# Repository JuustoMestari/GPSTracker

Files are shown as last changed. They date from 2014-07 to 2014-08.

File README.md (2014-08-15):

GPSTracker
==========

## Arduino

Arduino Pro mini 3.3V 8Mhz ( copy )

### Libraries

#### SoftwareSerial

In order to run the code properly, you need to modify **SoftwareSerial.h** (Arduino\libraries\SoftwareSerial) before compiling.
At line **42** change _SS_MAX_RX_BUFF to 256 : `#define _SS_MAX_RX_BUFF 256 `

#### NeoPixel

Please use the library in this repo. It has been modified to use Analog Port as well (Leds are connected to Analog 5)
If you want to make the modification yourself, replace all **PORTB** by **PORTC**  in Adafruit_NeoPixel.cpp (You won't be able to use the library with ports 8 to 13 tho...)
* Make a backup of the original file and use the modified version only to compile for this project !

[See here for port manipulation](http://www.arduino.cc/en/Reference/PortManipulation)

## Hardware

### TP4056

* Green LED ON - Red LED Blink -> **No battery**
* RED LED ON -> **Loading**
* GREEN LED ON -> **Loaded**

The module in this project uses a mini USB connector but micro USB versions are available on eBay.

[Module test](http://lygte-info.dk/review/Review%20Charger%20TP4056%20UK.html)

## Datasheets

## Eagle

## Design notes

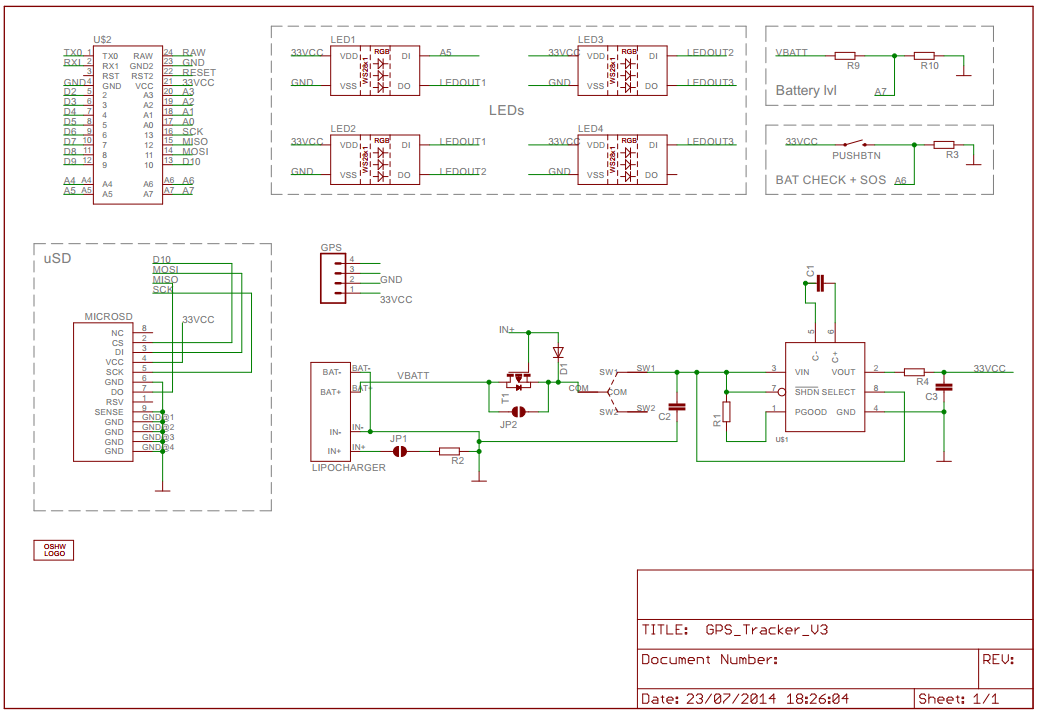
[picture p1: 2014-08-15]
GPS_Tracker_Schematic.PNG

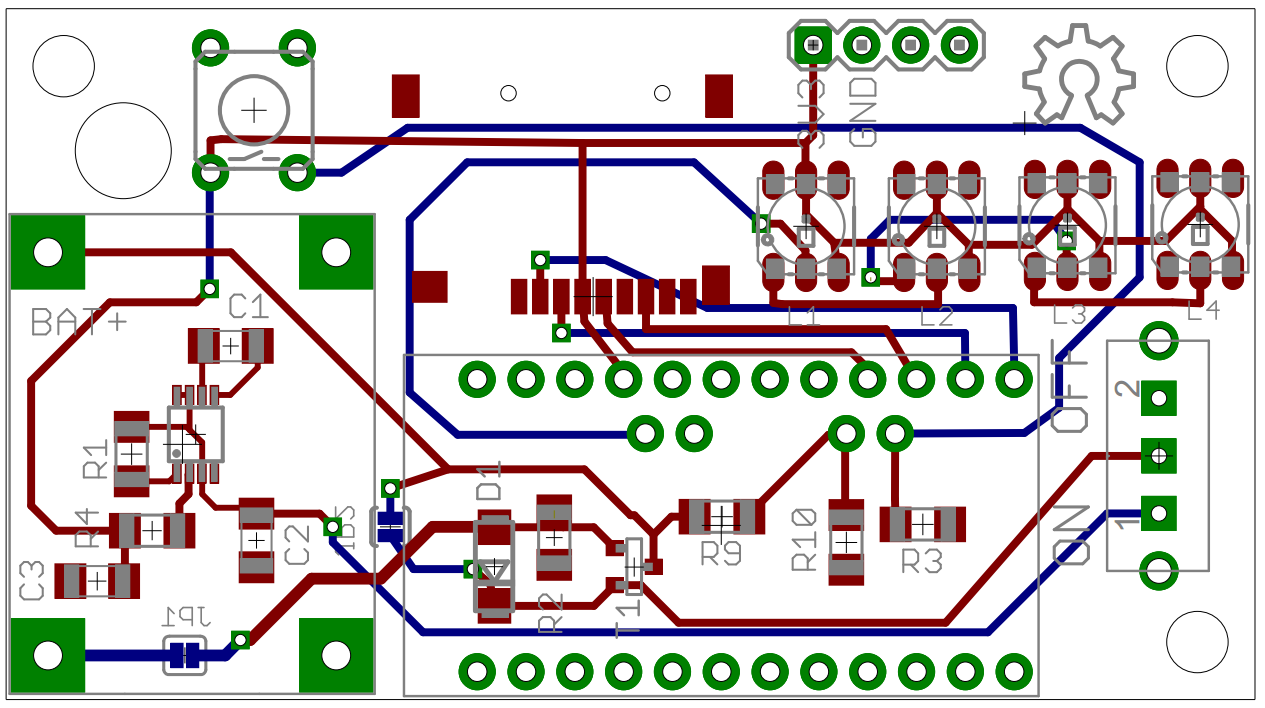
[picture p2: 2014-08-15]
GPS_Tracker_PCB.PNG

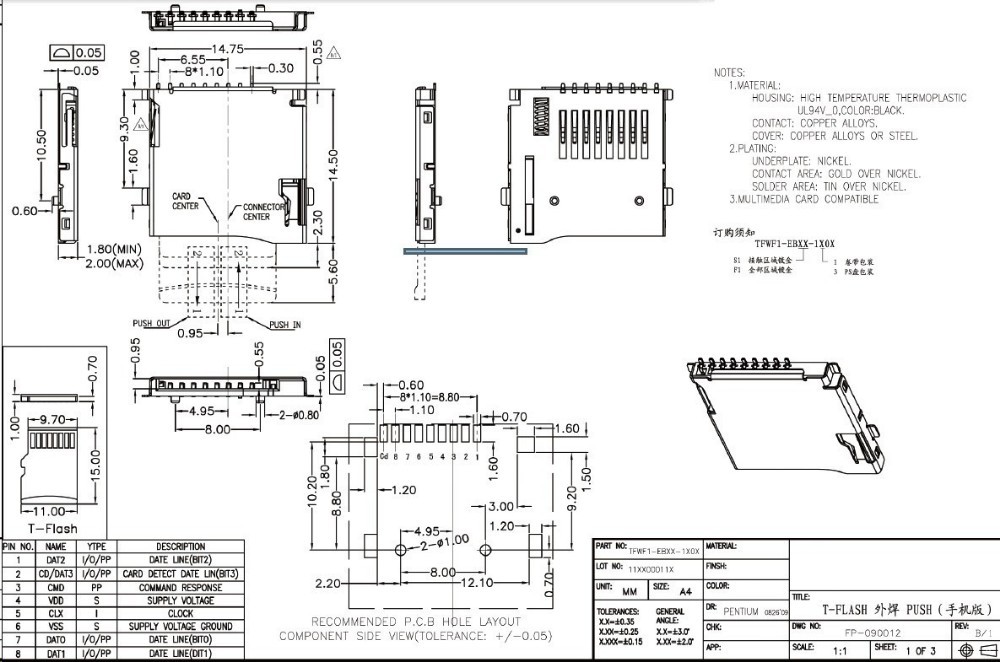
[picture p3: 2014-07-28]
Datasheets/SD_Socket.jpg

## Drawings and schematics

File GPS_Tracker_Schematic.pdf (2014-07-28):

# Battery lvl LEDs

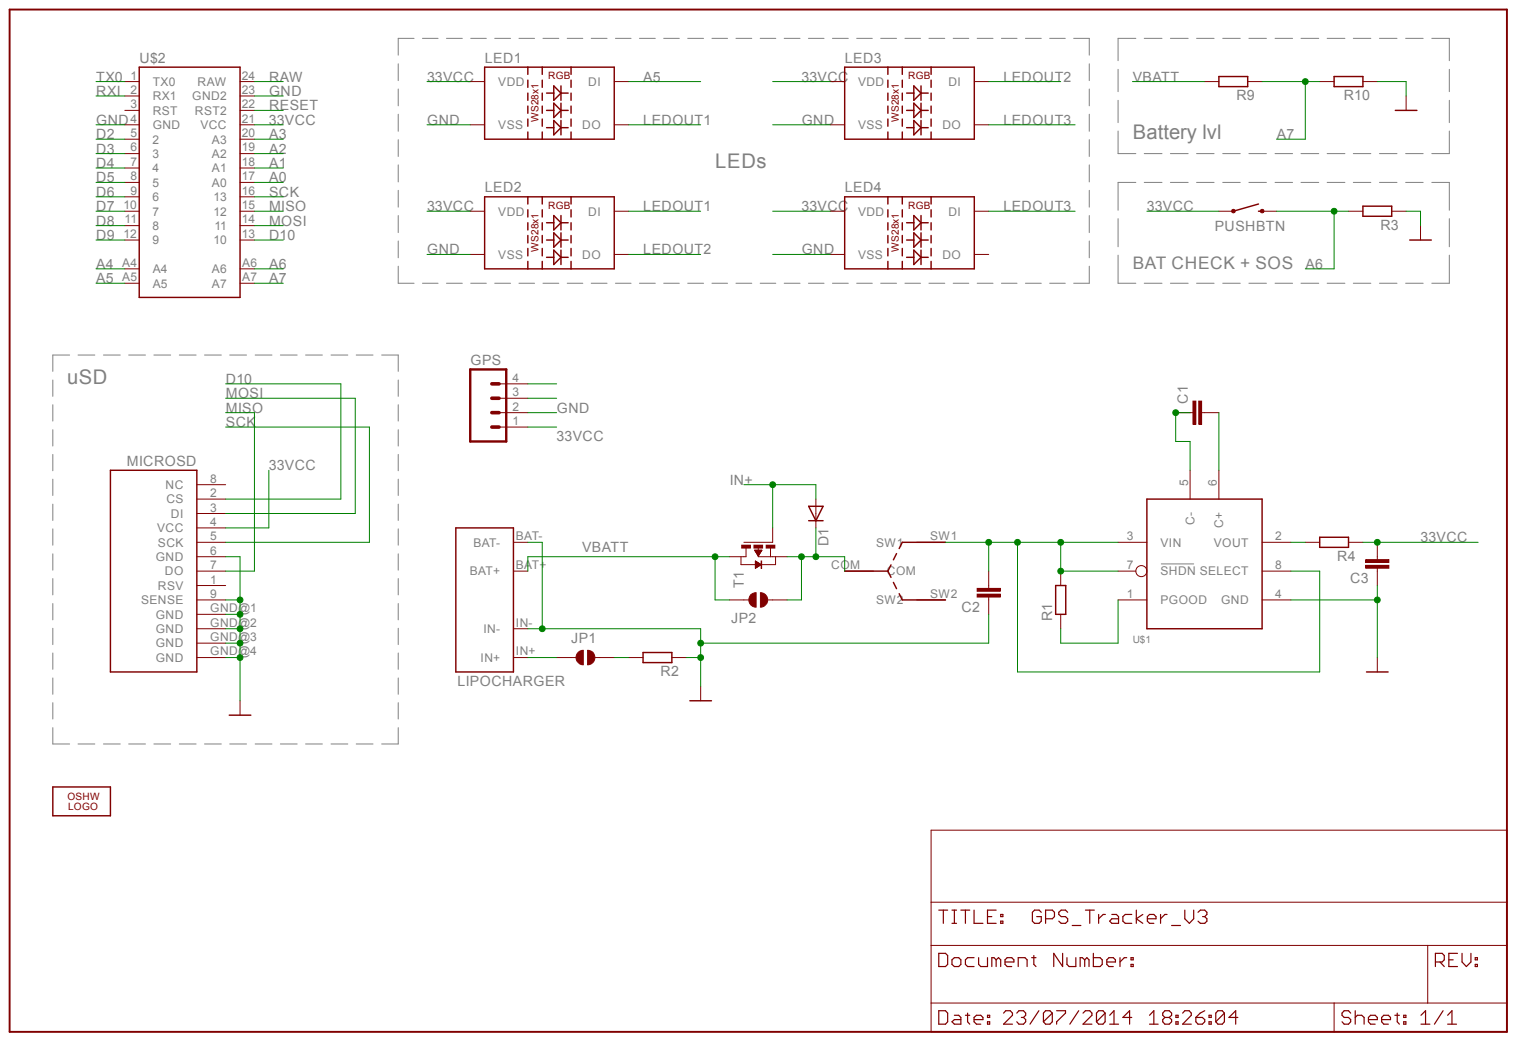
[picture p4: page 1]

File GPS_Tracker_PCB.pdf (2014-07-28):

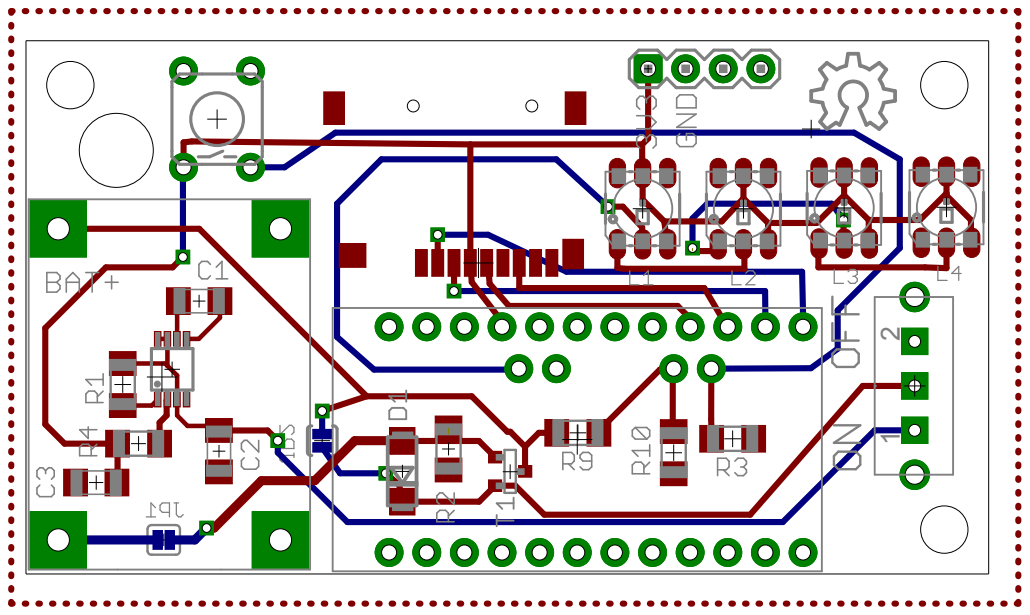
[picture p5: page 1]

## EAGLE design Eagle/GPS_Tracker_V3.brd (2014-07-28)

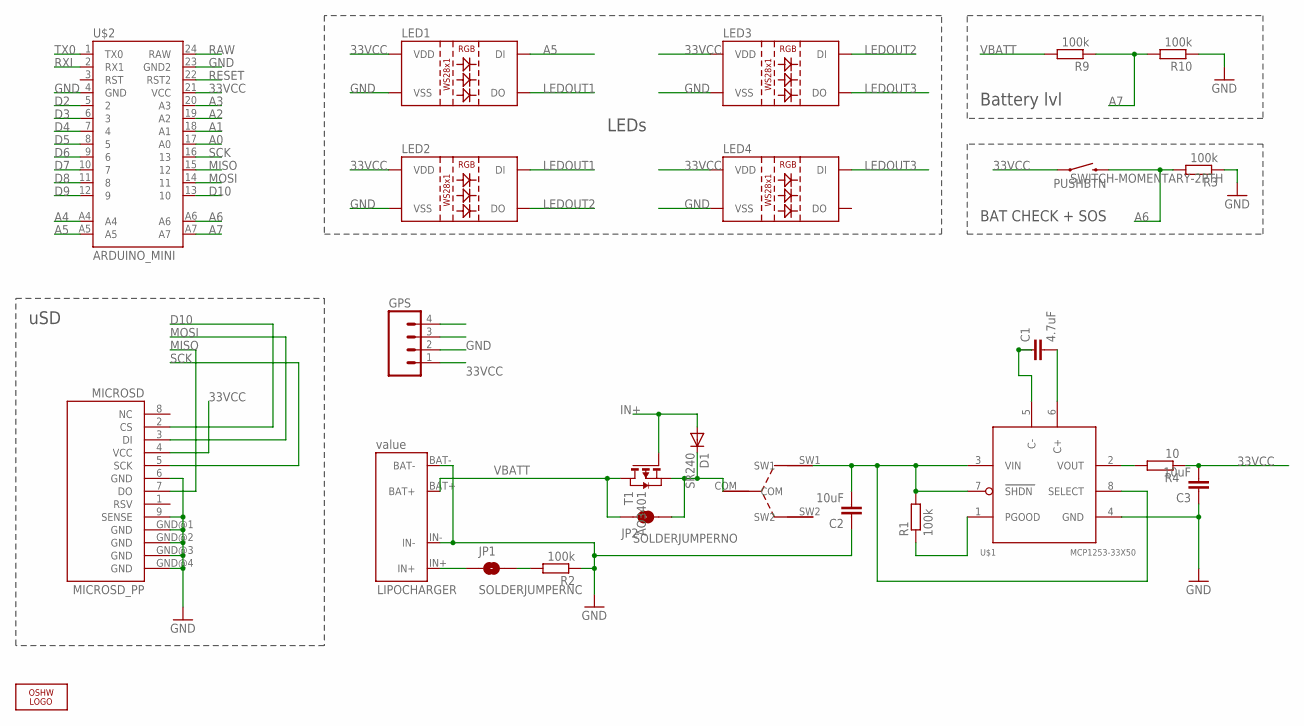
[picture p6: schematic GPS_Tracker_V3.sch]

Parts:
C1: 4.7uF; C1206
C2, C3: 10uF; C1206
D1: SR240; DO214AC
GPS: M04PTH; 1X04
JP1: SOLDERJUMPERNC; SJ_2S
JP2: SOLDERJUMPERNO; SJ_2S-NO
LED1, LED2, LED3, LED4: LED-TRICOLOR-5050-ICWS2811; LED-TRICOLOR-5050-IC
LIPOCHARGER: LIPO_CHARGER
LOGO1: OSHW_LOGO_10MILX0200-NT; OSHW_10X200_NOTEXT
MICROSD: MICROSD_PP
PUSHBTN: SWITCH-MOMENTARY-2PTH; TACTILE-PTH
R1, R2, R3, R9, R10: 100k; R1206
R4: 10; R1206
SW: SWITCHDAV; 5IL3MM
T1: AO3401; SOT-23
U$1: MCP1253-33X50; MSOP8
U$2: ARDUINO_MINI

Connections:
33VCC: C3.2, GPS.1, LED1.3 (VDD), LED1.5 (VDD), LED2.3 (VDD), LED2.5 (VDD), LED3.3 (VDD), LED3.5 (VDD), LED4.3 (VDD), LED4.5 (VDD), MICROSD.4 (VCC), PUSHBTN.1, R4.1, U$2.21 (VCC)
A0: U$2.17 (A0)
A1: U$2.18 (A1)
A2: U$2.19 (A2)
A3: U$2.20 (A3)
A4: U$2.A4
A5: LED1.2 (DI), U$2.A5
A6: PUSHBTN.3 (2), R3.2, U$2.A6
A7: R9.1, R10.2, U$2.A7
D2: U$2.5 (2)
D3: U$2.6 (3)
D4: U$2.7 (4)
D5: U$2.8 (5)
D6: U$2.9 (6)
D7: U$2.10 (7)
D8: U$2.11 (8)
D9: U$2.12 (9)
D10: MICROSD.2 (CS), U$2.13 (10)
GND: C2.1, C3.1, GPS.2, LED1.6 (VSS), LED2.6 (VSS), LED3.6 (VSS), LED4.6 (VSS), LIPOCHARGER.BAT-, LIPOCHARGER.IN-, MICROSD.6 (GND), MICROSD.9 (SENSE), MICROSD.GND@1 (GND), MICROSD.GND@2 (GND), MICROSD.GND@3 (GND), MICROSD.GND@4 (GND), R2.1, R3.1, R10.1, U$1.4 (GND), U$2.4 (GND), U$2.23 (GND2)
IN+: D1.A, JP1.2, R2.2, T1.3 (G)
LEDOUT1: LED1.1 (DO), LED2.2 (DI)
LEDOUT2: LED2.1 (DO), LED3.2 (DI)
LEDOUT3: LED3.1 (DO), LED4.2 (DI)
MISO: MICROSD.7 (DO), U$2.15 (12)
MOSI: MICROSD.3 (DI), U$2.14 (11)
unnamed: C2.2, R1.2, SW.SW1, U$1.3 (VIN), U$1.7 (SHDN), U$1.8 (SELECT)
unnamed: C1.1, U$1.5 (C-)
unnamed: C1.2, U$1.6 (C+)
unnamed: D1.C, JP2.2, SW.COM, T1.2 (S)
unnamed: R1.1, U$1.1 (PGOOD)
unnamed: R4.2, U$1.2 (VOUT)
unnamed: JP1.1, LIPOCHARGER.IN+
RAW: U$2.24 (RAW)
RESET: U$2.22 (RST2)
RXI: U$2.2 (RX1)
SCK: MICROSD.5 (SCK), U$2.16 (13)
TX0: U$2.1 (TX0)
VBATT: JP2.1, LIPOCHARGER.BAT+, R9.2, T1.1 (D)

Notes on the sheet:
Battery lvl
BAT CHECK + SOS
uSD
LEDs

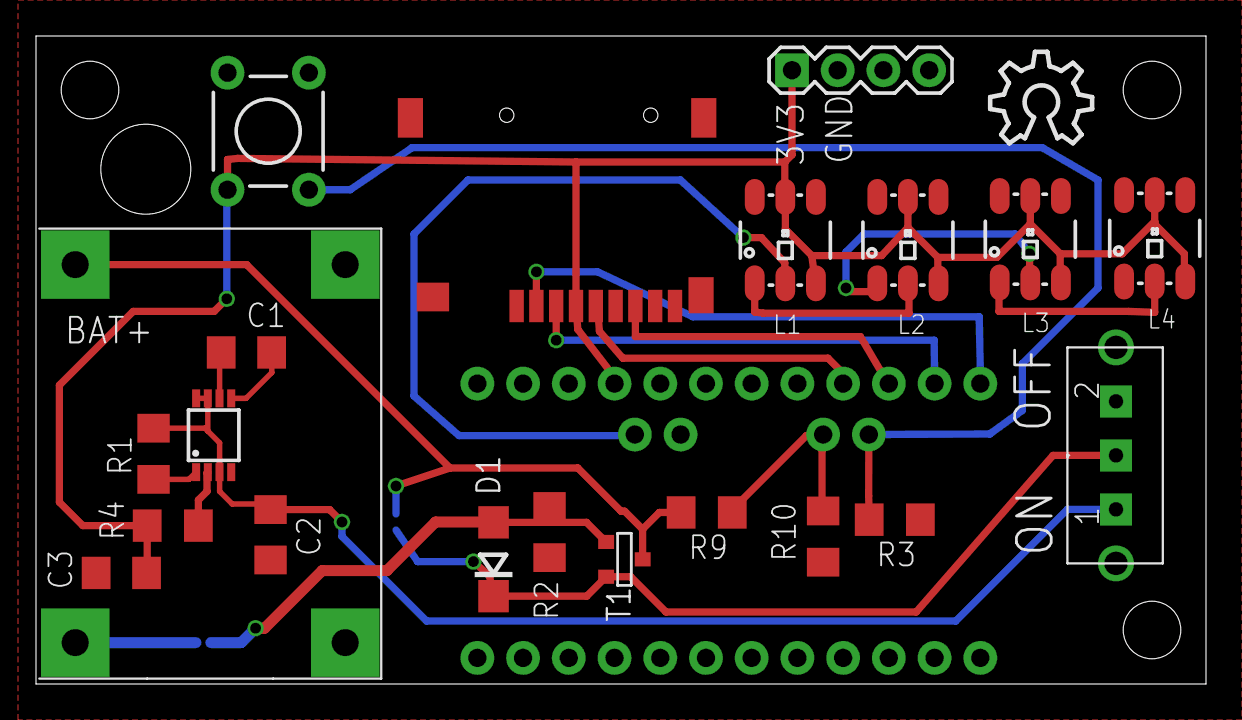
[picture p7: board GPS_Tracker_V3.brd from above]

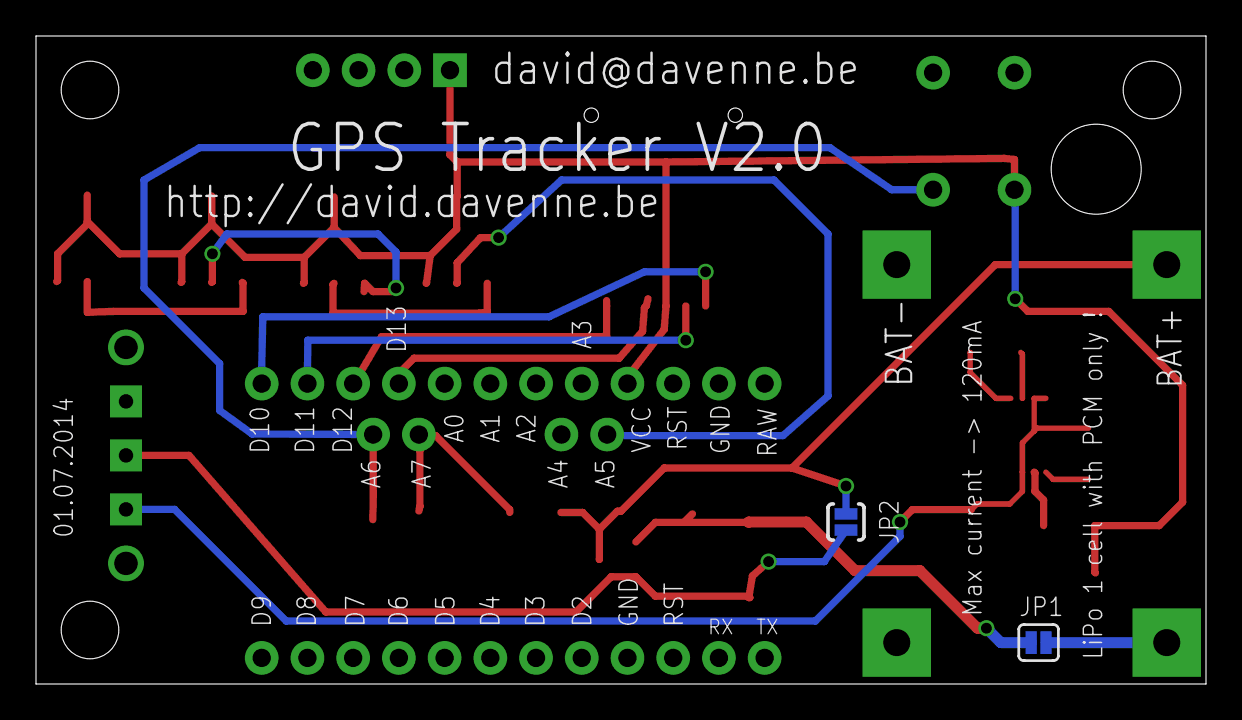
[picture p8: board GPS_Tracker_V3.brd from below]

Board: 2 copper layers, 65.0 x 36.0 mm, 25 parts (2 on the bottom side), 21 nets.

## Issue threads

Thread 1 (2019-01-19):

microcontroller code

mohamadnikan2013, 2019-01-19:
Hey,
I want to design a system just like you did and I find out I need to program the AVR  microcontroller. I searched in your repo but I didn't find any AVR microcontroller code!!
would you please push AVR microcontroller code? especially that part of the code that the AVR micro write data on the sd card.
thank you

JuustoMestari, 2019-01-19:
Hello,

The arduino code is available here : [GPS_v3.ino](../blob/master/Arduino/GPS_V3.ino)
or do you mean something else?

mohamadnikan2013, 2019-01-21:
yes
AVR code
for ATMEGA microprocessor

Closed 2019-01-26.

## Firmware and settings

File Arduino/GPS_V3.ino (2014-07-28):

#include <SoftwareSerial.h>
#include <EEPROM.h>

#include <SdFat.h>
#include <TinyGPS++.h>
#include <Adafruit_NeoPixel.h>

//ALPHA VERSION 0.1 ( 28/07/2014 )

#define recordFrequency 2000
#define saveStatic false
#define saveStaticMargin 0.00001 //~2meters

//SD
const int chipSelect = 10;
SdFat sd;

//GPS
TinyGPSPlus gps;
SoftwareSerial nss(9, 8);
double old_flat,old_flon;
//default recordFrequency untill getting valid info
int rF=1000;

//LEDs
Adafruit_NeoPixel strip = Adafruit_NeoPixel(4, 2, NEO_GRB + NEO_KHZ800);

//EEPROM
boolean isEEPROMset;

void setup()
{
    nss.begin(9600); 
    //Serial.begin(9600);
    strip.begin();
    strip.show(); // Initialize all pixels to 'off'
    strip.setBrightness(32);
  
    old_flat=0;
    old_flon=0;
    isEEPROMset=false;
    //eraseEEPROM();
    checkSD();  
}

void loop()
{
  
   unsigned long start = millis();
  
   while (millis() - start < rF)
  {
    feedgps();
  }
  
  if(gps.location.isValid() && gps.date.isValid() && gps.time.isValid())
  {
      //recording frequency becomes the one defined by the user
      rF=recordFrequency;
      
      //if coordinates haven't changed since last record, we don't record them.
      if(!saveStatic && (abs(old_flat-gps.location.lat())<=saveStaticMargin) && (abs(old_flon-gps.location.lng())<=saveStaticMargin))
      {
        swipeLEDS(strip.Color(255,0,255));
        return;
      }
      
      if (!sd.begin(chipSelect, SPI_HALF_SPEED)) 
       {
  	  displayError(3);
       }
      else
       {         
          char buffer[25];
          
          int iyear = gps.date.year();
          int imonth = gps.date.month();
          int iday = gps.date.day();
          int ihour = gps.time.hour();
          int imin = gps.time.minute();
          int isec = gps.time.second();
          
          sprintf(buffer,"LOGS/%d/%d/%d",iyear,imonth,iday);
          sd.mkdir(buffer);
          
          sprintf(buffer,"LOGS/%d/%d/%d/T_%d.CSV",iyear,imonth,iday,getFileName(iday,imonth,iyear-2000));
          ofstream sdlog(buffer, ios::out | ios::app);
          delay(100);
          
          //append data to file
          sdlog << dtostrf(gps.location.lat(), 9, 6, buffer) << "," << dtostrf(gps.location.lng(), 9, 6, buffer) << ",";
          sdlog <<  iday << "/" << imonth << "/" << iyear << " " << ihour << ":" << imin << ":" << isec << endl;                        
            
          if (!sdlog)
          {
             //failed to append text
             displayError(10);                                   
          }
           sdlog.close();
            
           //save new coordinates
           old_flat=gps.location.lat();
           old_flon=gps.location.lng(); 
           
           swipeLEDS(strip.Color(0,255,0));          
        }
  }
  else
  {
    swipeLEDS(strip.Color(0,0,255));
  }  
}

static bool feedgps()
{
  while (nss.available())
  {
    char c = nss.read();
    //Serial.write(c);
    if (gps.encode(c))
      return true;
  }
  return false;
}

int getFileName(int theday, int themonth, int theyear)
{
  int counter =EEPROM.read(0);
  if(isEEPROMset)return counter;
  
  int eeday=EEPROM.read(1);
  int eemonth=EEPROM.read(2);
  int eeyear=EEPROM.read(3);
  
  if(eeday!=theday || eemonth!=themonth || eeyear!=theyear)
  {
	EEPROM.write(1,theday);
	EEPROM.write(2,themonth);
        EEPROM.write(3,theyear);
        counter=0;
  }
  
  EEPROM.write(0,counter+1);
  isEEPROMset=true;
  //do something if counter >255
  return counter+1;
}

void checkSD()
{
  if (!sd.begin(chipSelect, SPI_HALF_SPEED)) 
  {
    displayError(6);
  }
  else
  {
    swipeLEDS(strip.Color(255,255,255));
  }
  delay(500);
}

void displayError(int errorNum)
{
  //Errors from 1 -> 15 (4 Leds = 4bits)

  clearLEDS();
  for(int i=0;i<4;i++)
  {
     if(bitRead(errorNum,i)) strip.setPixelColor(i, strip.Color(255,0,0));
  }
  strip.show();
  
  //halt here
  while(1) { }
}
void swipeLEDS(uint32_t Color)
{
  for(int i=0;i<4;i++)
  {
    strip.setPixelColor(i, Color);
    for(int j=0;j<i;j++)strip.setPixelColor(j, strip.Color(0,0,0));//optional line, comment for another swipe effect
    strip.show();
    delay(100);
  }
  clearLEDS();
}
void clearLEDS()
{
  for(int i=0;i<4;i++)strip.setPixelColor(i, strip.Color(0,0,0));
  strip.show();
}
void eraseEEPROM()
{
  for(int i=0;i<4;i++)EEPROM.write(i,0);//Serial.println(EEPROM.read(i));
}

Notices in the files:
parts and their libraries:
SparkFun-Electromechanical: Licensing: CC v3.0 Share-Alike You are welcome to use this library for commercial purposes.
